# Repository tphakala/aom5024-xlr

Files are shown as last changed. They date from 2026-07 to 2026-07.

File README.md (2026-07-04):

# AOM-5024 XLR pencil mic body

A one-piece, 3D-printable pencil-microphone body for the PUI Audio
**AOM-5024L-HD-R** electret capsule that screws directly into a genuine
Neutrik **NC3MXX** male XLR connector.

The design reuses the real connector's metal shell, pin insert and latch
unmodified - the printed part only replaces the cable bushing/boot, threading
into the shell's own internal thread and extending forward to carry the
capsule in a snug friction-fit pocket. Total length from capsule tip to the
connector's rear face is about **26 mm**, giving a very compact plug-on mic.

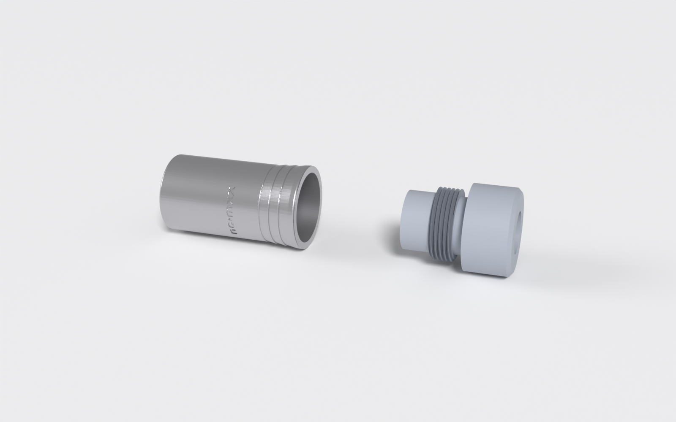
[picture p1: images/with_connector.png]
Printed housing next to a Neutrik NC3MXX connector


> **Compatibility warning:** this is designed for the NC3MXX exactly. That
> model has the bushing thread machined INSIDE the metal XLR shell. Older
> Neutrik revisions and the variants sold under the REAN brand have the
> thread on the OUTSIDE of the shell; those are NOT compatible with this
> design.

```
[capsule] [lip] [neck] [thread + wing ring] --> screws into --> [Neutrik NC3MXX]
                   one printed part                                   real connector
```

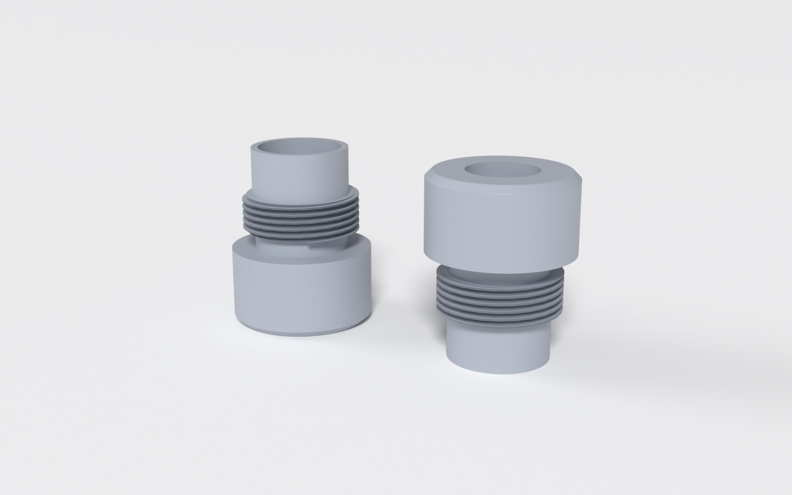
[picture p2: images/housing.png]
Housing from both ends


## Electronics

This body is designed for **simple P48 phantom-power circuitry - just a
resistor and a capacitor** - both of which fit inside the XLR connector
housing itself (on/around the pin insert's terminals). There is no PCB pocket
in the printed part and none is needed: the mic wires run from the insert
through the housing's 12 mm bore to the capsule's rear solder pads.

### Keep the cable short (about 20 m max)

The simple resistor + capacitor circuit is suitable for **short cable runs
only, roughly 20 meters at most**. Two reasons:

- **Cable capacitance rolls off the highs.** This circuit has no output
  buffer: the capsule's internal JFET drives the cable through the
  feed/coupling network, giving a source impedance of several kilohms.
  Together with the cable's conductor capacitance (roughly 50-100 pF per
  meter for typical mic cable) this forms an RC low-pass filter. At 20 m
  (about 2 nF) with a few-kilohm source, the corner sits just above the
  audio band; double or triple the length and the roll-off moves audibly
  into the treble, dulling the sound.
- **It is not a true balanced output.** The signal rides on one leg only, so
  the noise rejection of a genuinely balanced microphone is largely absent.
  The longer the run, the more hum and RF interference it picks up.

If you need a long run, either place the preamp/interface near the mic, or
upgrade the electronics to a buffered, impedance-balanced circuit (for
example a Schoeps- or Alice-style two-transistor front end) - though that
needs more board space than this connector housing offers.

## Weather sealing (optional)

The rear of the housing necks down to a narrow "seal zone" just behind the
collar. It works fine dry, but it also lets you weatherproof the joint between
the printed part and the metal shell with a single O-ring - handy for outdoor
mics.

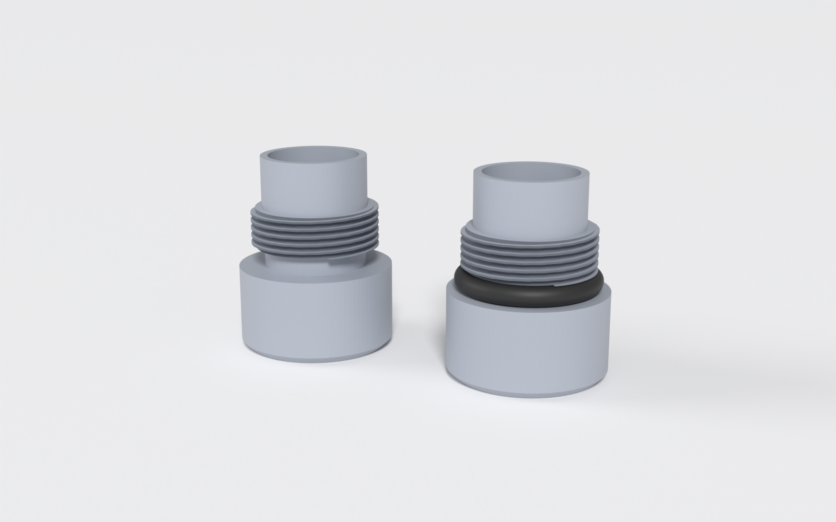
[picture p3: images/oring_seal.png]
The seal zone bare (left) and with an O-ring seated in it (right)


The NC3MXX shell has a smooth, unthreaded lip pocket just inside its rear
opening, above the internal threads. Drop a **~13 x 2.5 mm** (inner diameter x
cord) O-ring into that pocket, then thread the housing in as usual: the seal
neck passes through the ring and the shell bore squeezes it against the neck,
sealing the joint. No groove or glue is needed - the ring is captured between
the shell and the housing.

This was tuned and print-tested against a real NC3MXX shell (neck Ø13.5 mm,
seal-zone length 2.6 mm). If your shell or O-ring differ, the seal zone is
parametric: adjust `oring_neck_d`, `oring_neck_len` and `oring_neck_bore_d`
under **[O-ring seal zone]**, then re-print `fit_test_conn_thread` (it carries
the seal neck) and check the fit in your shell before a full print.

The front acoustic port cannot be sealed - it has to stay open for the mic - so
this weatherproofs the rear joint and the electronics cavity, not the capsule
face.

## Bill of materials

- **Neutrik NC3MXX** male XLR connector - must have the bushing thread
  machined *inside* the shell (see the compatibility warning above)
- **PUI Audio AOM-5024L-HD-R** electret capsule (or another capsule - see
  [Adapting to your capsule](#adapting-to-your-capsule))
- Resistor + capacitor for the P48 circuit
- Thin wire; optionally a dab of hot glue for permanent capsule retention
- Optional: a **~13 x 2.5 mm** (ID x cord) O-ring to weather-seal the
  housing/shell joint (see [Weather sealing](#weather-sealing-optional))

## Print the fit tests first

The connector thread is print-tested in ASA with a 0.4 mm nozzle and works
perfectly, and the capsule pocket is snug enough to hold the AOM-5024 in
place with friction alone (a small dab of hot glue would not hurt). Shells,
capsules, printers and materials vary, though, so both coupons are the cheap
way to confirm on your setup - they are tiny and print in minutes:

| coupon | verifies |
|---|---|
| `stl/fit_test_conn_thread.stl` | rear thread screws smoothly into *your* shell, and the wing ring reaches/pushes the pin insert into its seat |
| `stl/fit_test_capsule.stl` | front tip only - the capsule slides in snug and seats flat on the internal lip |

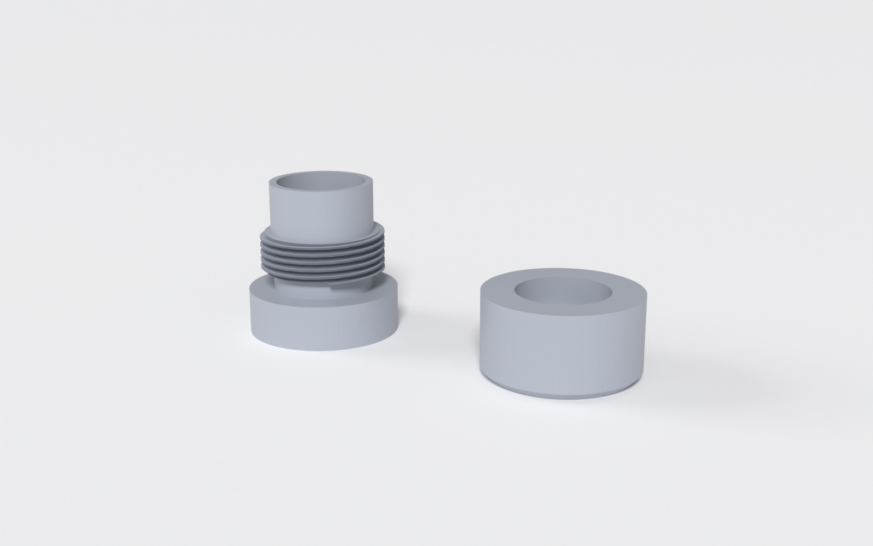
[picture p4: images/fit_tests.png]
Fit-test coupons


If the thread binds, reduce `conn_thread_major_d` ~0.1-0.2 mm at a time. If
the capsule is too tight in the pocket, raise `capsule_radial_clear` a step
(0.05 to 0.10); if it is loose, your capsule may be undersized - measure it
and set `capsule_od` to match.

## Printing

The design is print-verified: ASA with a 0.4 mm nozzle (Bambu Lab H2D) came
out right on the first try.

- **Material:** PETG, ABS or ASA (thread and wing-ring durability)
- **Layer height:** 0.16-0.20 mm, **perimeters:** 4
- **Infill:** 15 % is plenty; the part is mostly walls
- **Orientation:** front (capsule) end **down** on the bed, wing ring up.
  This matters: the tip chamfer is shaped to be self-supporting in this
  orientation. The internal lip prints as a narrow overhang step; it needs
  no support.

## Adapting to your capsule

Open `aom5024_xlr_mic.scad` in OpenSCAD - the parameters are organized for
the built-in Customizer (Window → Customizer). The pocket bore, pocket depth
and lip position all derive from two numbers under **[Capsule]**:

| parameter | default | meaning |
|---|---|---|
| `capsule_od` | 9.8 | capsule body **diameter** - measure yours with calipers (the AOM-5024 datasheet says 9.7 mm, an actual unit measured 9.8 mm) |
| `capsule_h` | 5.0 | capsule body **height/depth**, front face to rear face |
| `capsule_radial_clear` | 0.05 | extra pocket radius per side - a snug slip fit |
| `capsule_depth_clear` | 0.2 | extra pocket depth for height variation / solder blobs |

Other things you may want to tweak:

| parameter | default | meaning |
|---|---|---|
| `body_len` | 2.5 | length of the plain body tube between the capsule section and the collar - the simplest way to make the mic longer. See "Making the body longer (for a mic clip)" below; nothing else depends on it |
| `lip_overlap` | 0.6 | how far the retaining lip steps in below `capsule_od`. The lip opening (`capsule_od` minus this, 9.2 mm at defaults) is what the wires pass through - wide and easy |
| `lip_len` | 1.5 | axial thickness of the lip ring |

Guardrail `assert()`s fail the render loudly if a parameter combination
produces an oversized or broken part. After any change, print
`fit_test_capsule.stl` before a full housing.

## Making the body longer (for a mic clip)

The short default body barely protrudes from the connector. To seat the mic
in a standard mic clip you usually want a longer exposed barrel to clamp on.
Change **one** parameter, `body_len`.

The printed part has two halves:

```
capsule tip                       collar face │ (everything past here is INSIDE the shell)
|--- OUTSIDE the shell: 11.0 mm ---|           │--- INSIDE the shell: 14.7 mm (fixed) ---|
  capsule+lip 6.7   body_len 2.5   collar 1.8  │   seal neck + thread + wing ring
```

Only the length **outside** the shell is what a mic clip grips, and only
`body_len` is free to change - the capsule/lip section (6.7 mm) is set by the
capsule, and everything from the collar face inward (14.7 mm of seal neck,
thread and wing) is print-validated against the real shell and must stay put.
`body_len` adds 1:1 to both the exposed length and the total length; nothing
else moves.

So for a target **exposed** barrel length `L` (capsule tip to collar face):

```
body_len = L - 8.5      (that is, L minus the fixed 6.7 mm capsule section and 1.8 mm collar)
```

Example - double the exposed barrel from 11.0 mm to 22.0 mm, `body_len = 13.5`:

```
openscad -o stl/housing_long.stl -D 'part="housing"' -D 'body_len=13.5' aom5024_xlr_mic.scad
```

That makes the whole part 36.7 mm long while the thread and wing that thread
into the connector are untouched, so it still seats and seals exactly as the
default does. The barrel is a plain Ø20.4 mm cylinder (same as the shell OD),
which most standard mic clips grip fine.

> **Do not** reach for the `oring_neck_*` parameters for this. Despite the
> name, the code's "neck" is the O-ring **seal land inside the shell**, not
> the exposed body. Changing it drives the thread and wing deeper into the
> connector and breaks the print-validated seal fit. The exposed body you
> clamp a clip onto is `body_len`, and only `body_len`.

## Exporting STLs

```
openscad -o stl/housing.stl              -D 'part="housing"'              aom5024_xlr_mic.scad
openscad -o stl/fit_test_conn_thread.stl -D 'part="fit_test_conn_thread"' aom5024_xlr_mic.scad
openscad -o stl/fit_test_capsule.stl     -D 'part="fit_test_capsule"'     aom5024_xlr_mic.scad
```

Pre-rendered STLs with the default parameters are included in `stl/`.

## Assembly

1. Solder the P48 resistor/capacitor circuit on the XLR pin insert's
   terminals, with the two mic wires attached.
2. Feed the mic wires through the printed housing (rear opening → out the
   front).
3. Solder the wires to the capsule's rear pads.
4. Pull the wire slack back while pushing the capsule into the front pocket,
   until its rear face seats flat on the internal lip. Friction holds
   it; a small dab of hot glue makes it permanent.
5. Optional weather seal: drop a ~13 x 2.5 mm (ID x cord) O-ring into the
   connector shell's smooth internal lip pocket, just inside the rear opening
   above the threads (see [Weather sealing](#weather-sealing-optional)).
6. Screw the housing into the connector shell. The wing ring pushes the pin
   insert into its seat as the thread tightens; if fitted, the seal neck passes
   through the O-ring and the shell squeezes it home.

## Design notes

Dimensional provenance and the reasoning behind the geometry live in
[SPEC.md](SPEC.md). The preview images are rendered from the STLs with
`scripts/render_previews.py` (Blender, headless).

## License

[CC BY-NC 4.0](LICENSE) (Creative Commons Attribution-NonCommercial).
You are free to print, modify and share this design with attribution.
**Commercial use is not permitted** - do not sell prints or derivatives of
this design.

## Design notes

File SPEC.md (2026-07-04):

# AOM-5024 capsule housing for Neutrik NC3MXX - design notes

Engineering/provenance notes for `aom5024_xlr_mic.scad`: a parametric OpenSCAD
design for a one-piece pencil-mic body that holds a PUI Audio **AOM-5024L-HD-R**
electret capsule in a friction-fit pocket at the front and screws its rear end
into the **real** Neutrik **NC3MXX** metal shell's own internal thread (the
NC3MXX has threads machined inside the shell, where the stock cable
bushing/boot normally screws in). The real connector shell + pin insert are
used unmodified; only the bushing/boot is replaced, extended forward to carry
the capsule.

See `README.md` for the user-facing quick start (printing, assembly,
customization). This file records **where the numbers came from** and how
they were verified.

**Connector compatibility:** this fits the NC3MXX exactly. That model has
the bushing thread machined INSIDE the metal shell. Older Neutrik revisions
and REAN-branded variants have the thread on the OUTSIDE of the shell and
are NOT compatible with this design.

**Print-validated:** the housing has been printed in ASA with a 0.4mm nozzle
(Bambu Lab H2D) and came out right on the first try - thread fit, capsule
friction fit and seating all confirmed on real hardware. That print also
showed the then-current snap-fit fingers never actually flex in practice
(the capsule is inserted from the front, not pushed past them from the
rear), so they were simplified to the solid lip ring described below; the
exterior, pocket and thread are unchanged by that simplification.

> An earlier two-part variant (separate threaded cap holding the capsule) was
> retired in favor of this one-piece snap-fit design - fewer parts, shorter,
> and an assembly order that matches the actual build process (wires through,
> solder, push capsule in). Its threaded-cap joint also needed ~0.3mm of
> radial thread clearance to assemble on FDM, which let the cap sit visibly
> off-center on the housing; the one-piece design has no such joint.

## Files

- `aom5024_xlr_mic.scad` - the design (one printable part + two fit-test coupons)
- `stl/housing.stl` - the printable part
- `stl/fit_test_conn_thread.stl` - coupon: rear thread + wing ring stub
- `stl/fit_test_capsule.stl` - coupon: front tip only (pocket + lip),
  to test the capsule fit without printing the whole housing

All STL exports are re-rendered after every dimensional change and confirmed
manifold (`Simple: yes`, `Volumes: 2` in the OpenSCAD CLI render stats).

## How it goes together

```
[female XLR cable]  <--  [NC3MXX metal shell + pin insert] <-- [housing (one piece)]
                                                                   |
                                                     rear thread + wing ring
                                                                   |
                                                     body tube (wire routing)
                                                                   |
                                                     solid lip ring (depth stop)
                                                                   |
                                                     capsule pocket, open at the front
```

1. Feed mic wires through the housing from the rear opening, out the front.
2. Solder the wires to the capsule's rear pads (the AOM-5024L-HD-R has two
   solder pads, no lead wires).
3. Pull the wire slack back while pushing the capsule into the FRONT pocket,
   until its rear face lands flat on the lip. Friction holds it; a
   small dab of hot glue makes it permanent.
4. The housing's rear thread screws into the connector shell's internal
   thread. The **wing ring** (a solid ring just past the thread) reaches
   further into the shell than the thread does and pushes the connector's
   pin insert forward against its seat as the housing is tightened.

**The pocket + depth stop:** the capsule pocket is ONE consistent bore
diameter (`pocket_id` ≈ 9.9mm) for its entire depth, open straight out to the
front face - no separate, larger internal cavity behind a narrower opening.
Depth is set by a solid annular lip (`lip_len` = 1.5mm thick) starting at
exactly `capsule_h + capsule_depth_clear` - the capsule's rear face lands
flat against it. The lip's opening is `capsule_od - lip_overlap` (Ø9.2mm at
the defaults): only a 0.3mm/side step, plenty to stop the capsule, while
leaving the passage wide enough to feed the mic wires through with ease. Retention along the pocket walls is friction (≈0.1mm total
diametral clearance) plus optional glue. An earlier iteration used four
flexible snap fingers here instead; the ASA test print showed they only ever
act as this same lip (the capsule is inserted from the front and never cams
past them), so they were replaced with the simpler, stronger solid wall.

**The front outer edge** is a purely cosmetic 1.0mm-run 45° chamfer with a
0.3mm fillet where the flat front face meets the cylindrical OD - built so
the part is self-supporting when printed front-end-down (diameter is smallest
exactly at the tip and grows monotonically away from it).

## ⚠️ Estimated vs. measured - verify before committing filament

**A. Rear thread + wing ring (mates the REAL connector) - ESTIMATED**

Derived by mining the triangle mesh of a third-party commercial NC3MXX
bushing-replacement part (not included in this repository, and not a Neutrik
spec sheet). The values are confirmed working against one real NC3MXX shell
(full ASA print, threads in correctly), but shells vary - print
`fit_test_conn_thread.stl` to confirm them against *your* connector:

| parameter | value | how derived |
|---|---|---|
| `conn_thread_major_d` | 16.95 mm | crest diameter, mesh radius histogram |
| `conn_thread_minor_d` | 15.72 mm | root diameter, mesh radius histogram |
| `conn_thread_pitch` | 1.0 mm | z-spacing of repeated crest points at fixed θ |
| `conn_thread_len` | 5.3 mm | axial length of the threaded zone (~5 turns) |
| `wing_od` / `wing_id` | 14.0 / 12.0 mm | radius histogram above the thread zone |
| `wing_len` | 9.4 mm | axial length of that zone |

If the thread is tight, shave `conn_thread_major_d` down ~0.1-0.2mm at a time
(there's no clearance parameter for this thread - the mating female half is
real hardware, not something this file also prints).

The reference part's wing ring had a single slit (a flex spring); this design
uses a solid, uninterrupted ring instead. The slit is an opening a thin
component lead (e.g. the P48 resistor or capacitor on the insert's terminals)
could snag on while the housing is threaded in, and a rigid push does the
same job as the spring.

**B. Capsule - measured with calipers on an actual part**

AOM-5024L-HD-R datasheet nominal: 9.7±0.1mm dia × 5±0.2mm height. **Caliper
measurement on an actual unit: 9.8mm dia** - used for `capsule_od` since it
supersedes the datasheet for that specific part; measure yours. The pocket
bore is sized `capsule_radial_clear` = 0.05mm/side over that (≈9.9mm),
tightened over three passes after looser values (0.3, then 0.15, then
0.10mm/side) all felt loose in hand. Front face has a ~19-hole × Ø0.4mm sound
port cluster - not reproduced as printed holes (FDM can't resolve 0.4mm
reliably); the opening is left fully open instead.

**C. Capsule friction fit - print-verified on ASA**

The pocket holds the AOM-5024 in place with friction alone at the shipped
0.05mm/side clearance (verified on the ASA print); hot glue is optional
insurance. If a different capsule or material combination comes out too
tight, raise `capsule_radial_clear` one step (0.05 to 0.10); if loose,
measure the capsule and set `capsule_od` to match.

## Current computed dimensions (defaults as shipped)

| | value |
|---|---|
| Max OD anywhere on the print | 20.4 mm (`max_od`; print-compensated over a 20.3mm caliper measurement of the shell) |
| Overall length, capsule tip → connector rear face | ≈ 25.7 mm (`housing_len`) |
| Exposed length OUTSIDE the shell (capsule tip → collar face) | 11.0 mm = capsule/lip 6.7 + `body_len` 2.5 + collar 1.8. This is the barrel a mic clip grips |
| Length INSIDE the shell (collar face → wing tip, fixed) | 14.7 mm = seal neck + thread + wing; print-validated, do not change |
| Body tube length (`body_len`, freely adjustable) | 2.5 mm (the only free part of the exposed length; adds 1:1 to both exposed and overall length, nothing else depends on it) |
| Wire-passage bore (constant, behind the lip) | 12.0 mm (`wire_bore_d` = `wing_id`) |
| Capsule pocket | Ø9.9 mm × 5.2 mm deep (= `capsule_h` + `capsule_depth_clear`, one consistent bore, open to the front face) |
| Depth stop | solid lip ring, 1.5 mm thick (`lip_len`), opening Ø9.2 mm (`capsule_od - lip_overlap`), starting at `capsule_h + capsule_depth_clear` |
| Front outer edge (cosmetic) | 1.0mm-run 45° chamfer + 0.3mm fillet on the OD |
| Seal neck (O-ring seal zone) | Ø13.5 mm x 2.6 mm sealing land between collar and thread, wire bore necked to Ø9.8 mm there (`oring_neck_d` / `oring_neck_len` / `oring_neck_bore_d`); a Ø9.8→12 internal chamfer fillets the collar/neck junction and a Ø13.5→15.72 external cone leads the OD into the thread (`oring_neck_cham` / `oring_thread_lead`) - see below |

`max_od` is enforced by `assert()`s in the derived-values section - rendering
fails loudly if any parameter change pushes an OD past budget, rather than
silently printing an oversized part.

### Lengthening the exposed body (mic-clip fit)

The part splits at the collar face into an 11.0 mm section OUTSIDE the shell
(what a mic clip grips) and a fixed 14.7 mm section INSIDE the shell (seal
neck + thread + wing, print-validated - leave it alone). `body_len` is the
only free component of the exposed length and adds 1:1 to both the exposed and
overall length. For a target exposed length `L` (capsule tip to collar face):

```
body_len = L - 8.5          (L minus the fixed 6.7 mm capsule section + 1.8 mm collar)
```

Doubling the exposed barrel (11.0 -> 22.0 mm) is `body_len = 13.5`, giving a
36.7 mm total part with the thread/wing engagement unchanged. Verified by
measuring the exported STL bounding box (25.70 -> 36.70 mm, the 11.0 mm delta
landing entirely on the exposed body).

**Naming trap:** the code's `oring_neck_*` parameters are NOT this exposed
body. Despite "neck" in the name they are the O-ring **seal land inside the
shell**; changing them drives the thread and wing deeper and breaks the
print-validated seal fit. The exposed body is `body_len`, and only `body_len`.

## Re-exporting after edits

```
openscad -o stl/housing.stl              -D 'part="housing"'              aom5024_xlr_mic.scad
openscad -o stl/fit_test_conn_thread.stl -D 'part="fit_test_conn_thread"' aom5024_xlr_mic.scad
openscad -o stl/fit_test_capsule.stl     -D 'part="fit_test_capsule"'     aom5024_xlr_mic.scad
```

Threaded parts take ~15-100s to render at F6/CLI. **Always check the
`Volumes:` line in the render stats** (should read 2 for a single part).
Two solids that meet at a zero-thickness interface - stacked flush
end-to-end, or coinciding at an identical radius - can render as disjoint
volumes or non-manifold output in OpenSCAD's exact CGAL kernel, and whether
it manifests depends on the incidental numbers involved, so it can work by
coincidence until an unrelated parameter change breaks it. Every such
junction in this file carries a tiny (`eps` = 0.01mm) deliberate overlap,
and `finger_r_out` is margin-guarded with a `max()` for the same reason. If
you add or move any feature that stacks flush against another, give it the
same treatment.

## Suggested print settings

- **Material:** PETG or ABS/ASA (thread + wing-ring durability). ASA is
  print-verified.
- **Layer height:** 0.16-0.20 mm. 0.4mm nozzle is print-verified.
- **Perimeters:** 4 (thread strength, thin wing-ring walls).
- **Infill:** 15% is plenty (print-verified); the part is mostly walls.
- **Orientation:** front (capsule) end down on the bed, wing ring up. This is
  required, not optional: the tip chamfer is specifically built to widen as
  it prints upward in this orientation - printed the other way it would be a
  shrinking overhang. The internal lip prints as a narrow (0.35mm/side)
  overhang step over the pocket; it needs no support.

## O-ring seal zone (optional weather sealing)

The rear necks down to a Ø13.5 mm waist (`oring_neck_d`) for 2.6 mm
(`oring_neck_len`) between the collar and the thread, with the wire bore locally
necked to Ø9.8 mm (`oring_neck_bore_d`) so the sealing wall is a solid ~1.85 mm -
matching the rear thread-root wall (an earlier Ø8.0 bore left a 2.75 mm wall that
printed as an over-thick internal lip). The part works dry; it also accepts an
optional O-ring that seals the joint to the metal shell for outdoor use.

**Two chamfers tune the seal zone for FDM (printed tip-down, wing up).** Both were
added after a first O-ring print showed the earlier Ø8.0 choke as an over-thick
internal lip that sagged at its lower edge; the reworked seal zone below is
print-validated (ASA, 0.4 mm nozzle) - the underside and thread start come out
clean and the O-ring seals:

- **Collar/neck junction** (`oring_neck_cham`, 1.2 mm): the bore steps inward
  here (Ø12 → Ø9.8). A square step is a downward-facing internal overhang that
  sags, and a sharp stress riser at the neck root; a conical chamfer prints
  self-supporting and fillets the junction, strengthening the collar-to-neck
  connection.
- **Neck→thread lead-in** (`oring_thread_lead`, 1.2 mm): above the neck the
  thread core (Ø15.72) is wider than the neck (Ø13.5), so the thread would start
  as a floating ledge cantilevered over the narrower neck. An external cone ramps
  the OD (and the bore, back out to Ø12) up to the thread so the print widens
  gradually; it doubles as a thread entry taper. It is taken OUT of the thread
  length - the top turn sat in the shell's smooth lip and did not engage - so the
  engaging thread drops from ~5 to ~4 turns while the full 2.6 mm sealing land,
  the wing-tip depth and the 25.7 mm overall length are all unchanged.

**How it seals:** the NC3MXX shell has a smooth, unthreaded lip pocket just
inside its rear opening, above the internal threads (measured bore ~17 mm, depth
~2.5-2.6 mm - it matches the O-ring's width). An O-ring dropped into that pocket
is squeezed between the shell bore and the boot's seal neck as the boot threads
in. The ring lives in the shell, not on the boot, so no groove is needed.

**Provenance (measured / print-tuned against one real shell + one O-ring,
2026-07-03):** the O-ring is a 13 x 2.5 mm (ID x cord) nitrile ring; a 3 mm
cord over-squeezes at this neck/bore and will not fit. The neck diameter was
found by printing a row of stepped seal-test
plugs (Ø11.5-13.5 mm) and pushing each into the shell with the ring: Ø13.5
sealed snug/perfect - loose on the bare neck in air, tight once the shell bore
confines it (textbook radial seal). The thread + wing shift down by
`oring_neck_len` and the wing is shortened by the same amount
(`wing_len_net = wing_len - oring_neck_len`), so the overall length (25.7 mm)
and the wing-tip depth that seats the pin insert are unchanged - no over-travel.
`fit_test_conn_thread` carries the seal neck, so it doubles as the seal test;
verified sealing on the real shell. The shell's internal lip bore came from
caliper measurement, not the reference mesh (which is exterior-only in the rear
zone).

For a different shell or O-ring, tune `oring_neck_d` / `oring_neck_len` /
`oring_neck_bore_d` (and, if needed, the chamfer runs `oring_neck_cham` /
`oring_thread_lead`) and re-print `fit_test_conn_thread` to check the fit.

## Open items

- [ ] Decide if the 2.5mm `body_len` neck is too short in hand - one-line
      change either way.
- [ ] No strain relief at the connector's own rear - relies entirely on the
      shell + wing ring, same as commercial bushing replacements.
- [ ] Dimensions are only confirmed against one shell and one capsule so
      far; if a print doesn't fit for you, start from the fit-test coupons
      and the tuning advice above.
- [ ] O-ring seal zone confirmed against one shell + one O-ring only; the
      neck/lip numbers may need tuning for other shells or ring sizes (see the
      O-ring seal zone section for how).

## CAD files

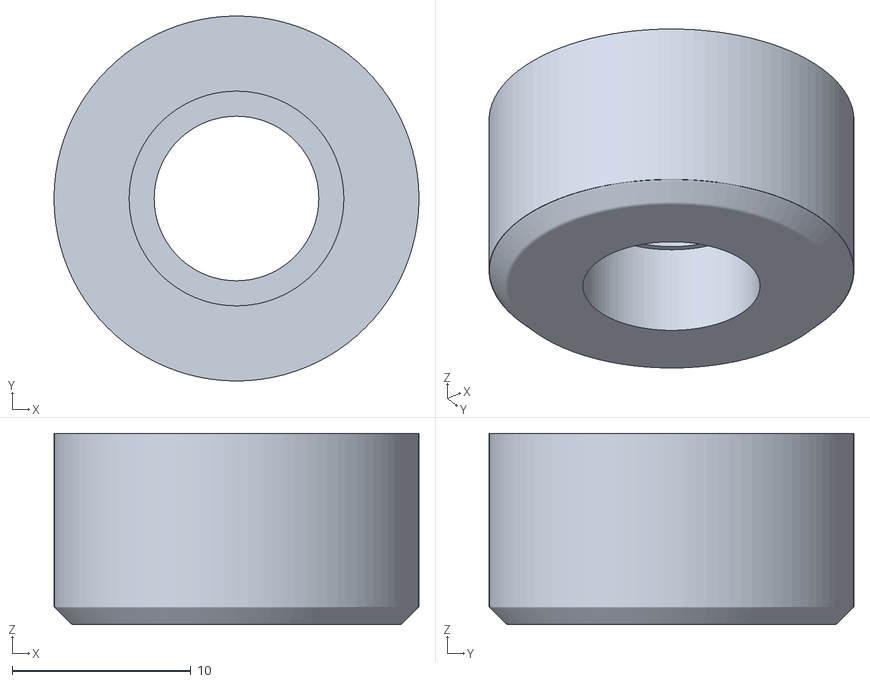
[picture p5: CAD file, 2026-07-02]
stl/fit_test_capsule.stl
20.4 x 20.4 x 10.7

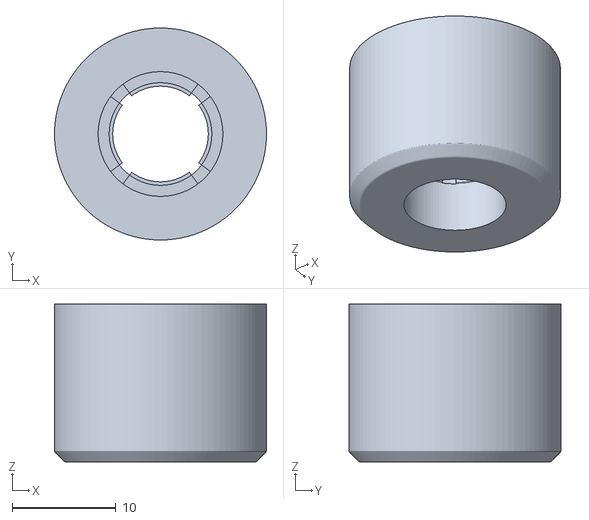
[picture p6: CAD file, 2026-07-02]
stl/fit_test_snap.stl
20.4 x 20.4 x 15.2

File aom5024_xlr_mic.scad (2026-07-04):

// =============================================================================
//  AOM-5024 CAPSULE HOUSING FOR NEUTRIK NC3MXX
// =============================================================================
//  A one-piece, 3D-printable pencil-microphone body that:
//
//    - holds an electret capsule (designed around the PUI Audio
//      AOM-5024L-HD-R) in a friction-fit pocket at the front, and
//    - screws its rear end into a real Neutrik NC3MXX male XLR connector,
//      using the shell's own internal thread (where the stock cable
//      bushing/boot normally screws in - requires the NC3MXX revision that
//      has this thread machined inside the shell; older revisions and REAN
//      variants with the thread OUTSIDE the shell are not compatible).
//
//  The connector's metal shell, pin insert and latch are used as-is; this
//  part only replaces the cable bushing/boot, extending forward to carry the
//  capsule. A necked "seal zone" just behind the collar optionally accepts an
//  O-ring for weather sealing (see [O-ring seal zone]); it works dry too.
//
//  ASSEMBLY
//    1. Feed the mic wires in through the rear opening and out the front.
//    2. Solder the wires to the capsule's rear pads.
//    3. Pull the wire slack back while pushing the capsule into the FRONT
//       pocket, until its rear face lands on the internal lip (the depth
//       stop). Friction holds it; add a dab of hot glue for a permanent
//       bond.
//    4. OPTIONAL weather seal: drop a ~13 x 2.5 (ID x cord) O-ring into the
//       shell's smooth internal lip pocket, just above its threads.
//    5. Screw the housing's rear thread into the connector shell. The wing
//       ring reaches past the thread and pushes the pin insert into its seat;
//       the seal neck passes through the O-ring and the shell squeezes it home.
//
//  ADAPTING TO YOUR CAPSULE
//    Set capsule_od and capsule_h under [Capsule] below - the pocket bore,
//    pocket depth and lip position all derive from those two numbers.
//    Print "fit_test_capsule" (just the front tip, minutes of print time) to
//    confirm the fit before printing a full housing.
//
//  FIT TESTS - PRINT THESE FIRST
//    The connector-thread dimensions were estimated from a third-party
//    reference mesh, NOT from a Neutrik spec sheet - verify against YOUR
//    connector before committing to a full print:
//      fit_test_conn_thread - rear thread + wing ring stub
//      fit_test_capsule     - front tip only: pocket + lip
//
//  EXPORT
//    openscad -o stl/housing.stl              -D 'part="housing"'              aom5024_xlr_mic.scad
//    openscad -o stl/fit_test_conn_thread.stl -D 'part="fit_test_conn_thread"' aom5024_xlr_mic.scad
//    openscad -o stl/fit_test_capsule.stl     -D 'part="fit_test_capsule"'     aom5024_xlr_mic.scad
//
//  PRINTING
//    Orientation: front (capsule) end down on the bed, wing ring up. The tip
//    chamfer is designed to be self-supporting in this orientation; the lip
//    prints as a narrow internal overhang step, no support needed. PETG /
//    ABS / ASA recommended, 4 perimeters, 0.16-0.20mm layers, 15% infill.
// =============================================================================


/* [Part] */
// Part to render/export
part = "housing"; // [housing, fit_test_conn_thread, fit_test_capsule]


/* [Capsule] */
// Capsule body diameter. Measure YOUR capsule with calipers - the AOM-5024L-HD-R datasheet says 9.7mm, but an actual unit measured 9.8mm
capsule_od = 9.8;
// Capsule body height, front face to rear face (pocket depth derives from this)
capsule_h = 5.0;
// Extra pocket radius PER SIDE over capsule_od - a snug slip fit. The pocket is one consistent bore, open straight to the front face
capsule_radial_clear = 0.05;
// Extra pocket depth behind the capsule's nominal seat - tolerance for capsule height variation and solder blobs on the rear pads
capsule_depth_clear = 0.2;
// How far the retaining lip behind the pocket bites below capsule_od, total
// diametral. The lip's opening is capsule_od - lip_overlap (9.2mm at the
// defaults) - a narrow annular step that stops the capsule but leaves the
// opening wide enough to pass the mic wires through with ease
lip_overlap = 0.6;
// Axial thickness of the lip ring
lip_len = 1.5;

// NOTE on the pocket design: a single consistent bore diameter is used for
// the entire pocket, opening straight out at the front face. Do not be
// tempted to add a narrower "aperture" in front of a wider pocket - if the
// opening is smaller than the pocket behind it, the capsule has room to
// rattle, tilt, and sink too deep in the gap. The lip provides the positive
// depth stop; the bore is just a straight, snug sleeve, and the capsule is
// retained by friction plus optional glue.


/* [Front tip] */
// Axial run of the 45-degree outer chamfer at the front tip (radial rise is equal)
tip_chamfer_len = 1.0;
// Fillet radius rounding the chamfer's corners
tip_fillet_r = 0.3;


/* [Connector thread - Neutrik NC3MXX] */
// These are ESTIMATES mined from a third-party reference mesh, not a Neutrik
// spec sheet. They are confirmed working against one real NC3MXX shell, but
// print fit_test_conn_thread and check against YOURS first. If the thread
// binds, shave conn_thread_major_d down ~0.1-0.2mm at a time (there is no
// clearance parameter: the mating female half is real hardware, not printed).

// Thread lead per turn
conn_thread_pitch = 1.0;
// Crest (outer) diameter of the male thread
conn_thread_major_d = 16.95;
// Root diameter of the male thread
conn_thread_minor_d = 15.72;
// Male tooth angular span, degrees. Beefy/printable - the real thread is finer, but we only need to grip the connector's flanks
conn_thread_tooth_ang = 100;
// Engagement length (~5 turns at 1.0 pitch)
conn_thread_len = 5.3;


/* [Wing ring] */
// A solid ring behind the thread that reaches deeper into the shell than the
// thread does, pushing the connector's pin insert forward against its seat
// as the housing is screwed home. (Some commercial bushing replacements slit
// this ring to make it a spring; solid is used here so no thin component
// lead on the insert's board can snag in a slit while threading in.)

// Wing ring outer diameter
wing_od = 14.0;
// Wing ring inner diameter (also sets the wire-passage bore)
wing_id = 12.0;
// Wing ring length
wing_len = 9.4;


/* [Body] */
// Widest OD allowed anywhere on the print. 20.3mm = caliper measurement of a real NC3MXX shell, +0.1mm print-shrinkage compensation so the printed part sits flush
conn_shell_od = 20.4;
max_od = 20.4;
// Collar length - the flush shoulder that lands on the connector's rear face
collar_len = 1.8;
// Body tube length between the capsule shoulder and the collar. This is the
// ONLY free part of the length that sits OUTSIDE the connector shell (the barrel
// a mic clip grips): exposed length = 6.7 (capsule/lip) + body_len + 1.8 (collar),
// = 11.0mm at the default. Everything past the collar (seal neck + thread + wing)
// is inside the shell and print-validated - do not touch it. For a target exposed
// length L, set body_len = L - 8.5 (e.g. 13.5 doubles the exposed barrel to 22mm).
// NOTE: this is the exposed body, NOT the oring_neck_* "seal neck" (that is inside
// the shell). Adds 1:1 to the overall length; nothing else depends on it
body_len = 2.5;


/* [O-ring seal zone] */
// The boot necks down to a waist between the collar and the thread. It works
// as-is (dry), and it also lets you add an OPTIONAL O-ring for weather sealing:
// seat a 13 x 2.5mm (ID x cord) O-ring in the NC3MXX shell's smooth internal
// lip pocket just above its threads (a 3mm cord over-squeezes and will not fit),
// threads, then thread the boot in - the neck passes through the ring and the
// shell bore squeezes it against the neck to seal. No groove is needed: the
// ring lives in the shell, not on the boot. Print-tested sealing on a real shell.
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

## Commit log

2026-07-02 Initial release: one-piece snap-fit AOM-5024 mic body for Neutrik NC3MXX
    Parametric OpenSCAD pencil-mic body holding a PUI Audio AOM-5024L-HD-R
    electret capsule in a snap-fit pocket, screwing into the real NC3MXX
    shell's internal bushing thread. Includes fit-test coupons for the
    connector thread and the capsule snap fit, pre-rendered STLs, and
    design/provenance notes in SPEC.md.
    [aom5024_xlr_mic.scad, fit_test_snap.stl]
2026-07-02 Add rendered preview images, print-verified settings, compatibility notes
    - Blender-rendered previews (housing, fit-test coupons, and alongside a
    Neutrik NC3MXX connector) plus the headless render script
    - README: NC3MXX-only compatibility warning (inside-shell thread; older
    revisions and REAN variants with outside threads do not fit), P48 note,
    print-verified settings (ASA, 0.4mm nozzle, 15% infill)
    - SPEC: drop the development revision history, fold the durable
    engineering notes into their sections, mark the design print-validated
2026-07-02 Replace snap fingers with a solid shoulder; render connector without boot
    The ASA test print showed the snap fingers never flex in practice: the
    capsule is inserted from the front, so the fingers only ever acted as a
    lip stopping it from being pushed deeper. Replaced with a solid 1.5mm
    shoulder wall with a 4mm wire-pass hole (simpler, stronger, and the same
    proven stop geometry as the retired threaded-cap variant). Housing
    shortens to ~25.7mm; exterior, pocket and thread are unchanged.
    - fit_test_snap coupon renamed to fit_test_capsule
    - with_connector render now shows the NC3MXX shell without its stock
    boot, since the printed housing replaces the boot
    - README/SPEC: front-insertion assem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
    [aom5024_xlr_mic.scad, fit_test_capsule.stl]
2026-07-02 Widen capsule stop into a thin lip ring; fix connector render
    The solid shoulder's 4mm wire-pass hole was too small to feed the mic
    wires through comfortably. The stop is now a thin annular lip, opening
    capsule_od - lip_overlap (9.2mm at defaults) - the same effective lip
    geometry the old snap-finger nubs formed, as one solid ring. New
    lip_overlap/lip_len parameters replace shoulder_len/wire_pass_d.
    Connector render fixes: the Neutrik STEP is one fused solid, so the
    boot is now removed with a capped planar slice at the shell rear rim
    (no more floating skin fragments), the bushing-thread opening is carved
    back in with a Blender boolean, and the housing is flipped so its
    thread faces the shel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
    [aom5024_xlr_mic.scad, fit_test_capsule.stl]
2026-07-02 Add CC BY-NC 4.0 license
    Free to print, modify and share with attribution; commercial use is
    not permitted.
2026-07-02 Fix connector render: cut at the true shell end
    The three deep grip grooves in the previous render belong to the boot,
    not the shell - the real NC3MXX housing ends at its three ridges, the
    rearmost (longest) one being the end of the metal shell. The slice
    plane moved from z=28.3 to z=20.8 accordingly.
2026-07-02 README: note that the simple P48 circuit suits short cables only
    Unbuffered kilohm-level source impedance plus cable capacitance forms
    an RC low-pass that eats treble on long runs, and the single-leg signal
    lacks true balanced-line noise rejection - keep runs to about 20 m.
2026-07-03 Add optional O-ring weather seal (seal neck) to the housing
    The rear now necks down to a Ø13.5 x 2.6mm seal zone between the collar and
    the thread. It works dry; dropping a ~13x3 O-ring into the NC3MXX shell's
    smooth internal lip pocket weatherproofs the housing/shell joint - the shell
    bore squeezes the ring against the neck. The wing is shortened by the neck
    length so the wing-tip depth (which seats the pin insert) and the overall
    length are unchanged. Print-validated sealing on a real shell.
    - scad: permanent seal neck + locally necked wire bore for a solid seal wall
    - README/SPEC: weather-sealing section + measured provenance
    - re-rendered previews; added images/oring_seal.png (with/wit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
    [aom5024_xlr_mic.scad]
2026-07-03 Correct O-ring spec to 13 x 2.5 mm
    The seal O-ring is a 13 x 2.5 mm (ID x cord) ring, not 13 x 3: a 3 mm cord
    over-squeezes at the Ø13.5 neck / ~17 mm shell bore and will not fit. Geometry
    is unchanged (the neck was tuned to the real ring); this only fixes the stated
    spec in the README, SPEC and .scad, and thins the rendered cord in
    images/oring_seal.png to match.
    [aom5024_xlr_mic.scad]
2026-07-03 Refine O-ring seal zone for FDM: thinner wall + two chamfers
    Open the seal-neck bore Ø8.0 -> Ø9.8 so the sealing wall (~1.85mm) matches the
    thread-root wall instead of the old over-thick ~2.75mm internal lip, and add two
    chamfers that came out clean on an ASA print:
    - oring_neck_cham: internal chamfer at the collar/neck junction, replacing a
    square downward-facing bore step (which sagged when printed tip-down) and
    filleting/reinforcing the neck root.
    - oring_thread_lead: external neck->thread lead-in cone so the thread no longer
    starts as a floating ledge over the narrower neck. Taken out of the thread
    length, so the 2.6mm sealing land, wing-tip depth and 25.7mm overall length are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
    [aom5024_xlr_mic.scad]
2026-07-04 Add longer-body variant for mic-clip mounting + document how to lengthen
    The exposed barrel outside the shell (capsule tip -> collar face) is 11.0mm at
    the default body_len=2.5. Only that section is what a mic clip grips, and only
    body_len changes it: exposed = 6.7 (capsule/lip) + body_len + 1.8 (collar),
    adding 1:1 to the overall length. Everything past the collar (seal neck +
    thread + wing, 14.7mm) is inside the shell and print-validated, so it stays put.
    - stl/housing_long.stl: body_len=13.5 doubles the exposed barrel to 22.0mm
    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
    [aom5024_xlr_mic.scad]
